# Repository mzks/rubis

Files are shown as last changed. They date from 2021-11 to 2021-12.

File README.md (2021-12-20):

# rubis








ADC board for 16 channels Slow Control on Raspberry pi.
This repository provides board design and control software.

## Demo
 - 30 seconds to start

rubis_demo_comp

 - Web watching demo
demo
It is easy to watch your sensors with rubis + Grafana

 - PCB view on Raspbery Pi


## Feature

 - Standalone
 - Inexpensive
 - Multi channels (16 ch) and additional connectors (4 ch)
 - Including CLI software (This!)

## Hardware components
 - rubis board - less than 5 dollars at elecrow 
 - Raspberry Pi (1B+, 2B, 3B, 3B+, 4B, Zero)
 - [PIN Socket](https://akizukidenshi.com/catalog/g/gC-00085/) 
 - [ADC Board](https://www.marutsu.co.jp/pc/i/574270/) * 1--4 / 20 dollers per board
 - [BNC Connector](https://akizukidenshi.com/catalog/g/gC-00134/) ( * 4, optional)
 - [SMA Connector](https://akizukidenshi.com/catalog/g/gC-02569/) ( * 4, optional)
 - LEMO Connector (Optional)

## Hardware

You need to connect the four GPIO pins arranged in a square (Pin 3 -- SDA, Pin 4 -- 5V, Pin 5 -- SCL, Pin 6 -- GND).
 - [Circuit diagram](https://github.com/mzks/rubis/blob/main/hardware/rubis_circuit.pdf)
 - [3D view](https://github.com/mzks/rubis/blob/main/hardware/rubis.step)
 - [KiCad files](https://github.com/mzks/rubis/blob/main/hardware)

## Software

### Install
Before run, enable I2C on Raspberry Pi. (`sudo raspi-config`)
Then, you can find the i2c devices like this.
```
> sudo i2cdetect -y 1
     0  1  2  3  4  5  6  7  8  9  a  b  c  d  e  f
00:          -- -- -- -- -- -- -- -- -- -- -- -- --
10: -- -- -- -- -- -- -- -- -- -- -- -- -- -- -- --
20: -- -- -- -- -- -- -- -- -- -- -- -- -- -- -- --
30: -- -- -- -- -- -- -- -- -- -- -- -- -- -- -- --
40: -- -- -- -- -- -- -- -- 48 49 4a 4b -- -- -- --
50: -- -- -- -- -- -- -- -- -- -- -- -- -- -- -- --
60: -- -- -- -- -- -- -- -- -- -- -- -- -- -- -- --
70: -- -- -- -- -- -- -- --
```
If you will use an old raspberry pi, run `sudo apt install libatlas-base-dev` to use `numpy` (This tool doesn't depend on `numpy`).

Then, type `pip3 install rubis`
The `rubis` binary will be provided at `~/.local/bin/rubis`
You want mysql store, please see `Database setting` below.

### Usage
When you execute `rubis` without option, logging immidiately starts with default configurations.
You can use your custom configuration file with `-c` option.

`rubis -g` generates template config file.
Edit them, then run `rubis -c custom_config.json`.
At the **strong** request of the author's supervisor, the following commands are available to people in CYGNUS (dark matter search experiment) without creating or editing a new configuration file.
```
rubis -c cygnus
```
In addition of `cygnus`, `one_board` and `mysql` configurations are pre-defined.

Some configurations can be overwrited with command line options.
`rubis -h` provides option descriptions.
The output file format is CSV/MySQL.

As a default, the csv files like `sc-20211029-75enrt.csv` are created.
The `75enrt` is a unique hash created by configurations.
The hash helps separation not to mix files taken with different configurations.
The CSV format is like that.
```
time,ch1,ch2,ch3,ch4,ch5,ch6,ch7,ch8,ch9,ch10,ch11,ch12,ch13,ch14,ch15,ch16
2021-10-29 00:49:50, 0.5481417, 0.5476417, 0.5483917, 0.5476417, 0.5432666, 0.5430166, 0.5441416, 0.5433916, 0.5486417, 0.5478917, 0.5482667, 0.5477667, 0.5441416, 0.5446416, 0.5440166, 0.5440166
2021-10-29 00:50:51, 0.5486417, 0.5483917, 0.5475167, 0.5476417, 0.5437666, 0.5435166, 0.5435166, 0.5436416, 0.5482667, 0.5483917, 0.5485167, 0.5481417, 0.5451416, 0.5451416, 0.5438916, 0.5437666
2021-10-29 00:51:51, 0.5480167, 0.5478917, 0.5480167, 0.5475167, 0.5432666, 0.5431416, 0.5430166, 0.5437666, 0.5482667, 0.5481417, 0.5481417, 0.5480167, 0.5445166, 0.5436416, 0.5443916, 0.5443916
2021-10-29 00:52:51, 0.5487667, 0.5481417, 0.5481417, 0.5481417, 0.5437666, 0.5437666, 0.5438916, 0.5435166, 0.5487667, 0.5482667, 0.5483917, 0.5478917, 0.5448916, 0.5440166, 0.5442666, 0.5438916
2021-10-29 00:53:52, 0.5482667, 0.5486417, 0.5476417, 0.5477667, 0.5438916, 0.5437666, 0.5432666, 0.5435166, 0.5487667, 0.5481417, 0.5481417, 0.5485167, 0.5445166, 0.5440166, 0.5441416, 0.5440166
2021-10-29 00:54:52, 0.5482667, 0.5478917, 0.5477667, 0.5478917, 0.5433916, 0.5430166, 0.5436416, 0.5438916, 0.5487667, 0.5487667, 0.5488918, 0.5478917, 0.5451416, 0.5447666, 0.5442666, 0.5441416
2021-10-29 00:55:53, 0.5487667, 0.5480167, 0.5478917, 0.5475167, 0.5441416, 0.5437666, 0.5435166, 0.5433916, 0.5487667, 0.5480167, 0.5483917, 0.5482667, 0.5452666, 0.5450166, 0.5448916, 0.5441416
2021-10-29 00:56:53, 0.5487667, 0.5483917, 0.5482667, 0.5481417, 0.5440166, 0.5438916, 0.5441416, 0.5443916, 0.5491418, 0.5487667, 0.5483917, 0.5482667, 0.5446416, 0.5442666, 0.5441416, 0.5445166
2021-10-29 00:57:54, 0.5478917, 0.5483917, 0.5480167, 0.5480167, 0.5441416, 0.5438916, 0.5440166, 0.5442666, 0.5491418, 0.5488918, 0.5488918, 0.5481417, 0.5450166, 0.5443916, 0.5441416, 0.5442666
```

The `-r` option makes "dry-run".
With the option, this rubis works on general system not raspberry pi even without ADS board.
It helps to know how rubis works.

The `-l` option show rubis log.
It helps to find the logfile place and configuration with hash.

If you miss a config to generate hash, `-b` option helps you.
`rubis -b g2hlpc` generates the config file run before.

The `-q` option kill all rubis processes.
With the `-s` option, rubis uses the stored cofiguration used in the previous run.

For analysis with pandas dataframe, it is easy to extract the csv files.
```
import pandas as pd
from glob import glob

hash_str = '75enrt'
df = [pd.read_csv(name, parse_dates=[0], index_col=0) for name in sorted(glob('./*'+hash_str+'.csv'))]
df = pd.concat(df)
```

### Config option

| Configure name | Description | Option | Overwrite option |
| --- | --- | --- | --- |
| `path` | Path to store the data | Default: "./" | -p |
| `file_header` | File header of generated file | Default: "sc" | -f |
| `naming` | Naming style of file | `'date_hash.csv'`, etc. Available keywords : 'head', 'date', 'id', 'hash', 'host' | -n |
| `rubis_id` | rubis id (string) | Used to identify your rubis board | -i |
| `time_interval_sec` | Data taking time interval (sec)  | Default: 10 | -t |
| `available_boards`  | List of available ADS1115 boards | Default: [1,2,3,4] | -a |
| `output` | Output format | `"csv"`, `"db"`, or `"both"` | -o |
| `delimiter` | Delimiter for csv output | `","`, `" "`, `"space"`, etc. | -d |
| `commentout_string` | Strings to be added on the csv file header | default: "" | |
| `time_format` | Time column format | "timestamp", "datetime" (default), or strftime format (for example, "%H:%M:%S") |  |
| `boards` | Setting for each ADS1115 board | `"gain"` option is available | |
| `sources` | Setting for each channels | | |

If you select `naming` including "date", a new file will be created day by day.

The sources should be set like,
```
"1":{
    "name": "ch1",
    "description": "channel 1",
    "type": "volt"
    },
"2":{
    "name": "ch2",
    "description": "channel 2",
    "type": "linear"
    "a": 2.0,
    "b": 1.2
    },
```
The `name` is used for csv header. For the `type`, `"volt"`, `"raw"`, `"millivolt"`, and `"linear"` are available.
`"linear"` returns the value `"a" * (volt) + "b"`. The "a" and "b" should be written in the config file, for each sources.

## Database setting
If you want database store, do like that additionaly
```
sudo apt install mariadb-server
sudo mysql -u root
MariaDB [(none)]> UPDATE mysql.user SET password=password('newpassword') WHERE User = 'root';
MariaDB [mysql]> UPDATE mysql.user SET plugin='' WHERE User='root';
MariaDB [mysql]> GRANT ALL PRIVILEGES ON *.* TO 'root'@'localhost' identified by 'newpassword' with grant option;
MariaDB [mysql]> exit
sudo systemctl restart mysql
```
You need an external access, please make a user.
```
CREATE USER 'rubis'@'10.37.%' IDENTIFIED BY 'password';
GRANT ALL ON *.* TO 'rubis'@'10.37.%';
FLUSH PRIVILEGES;
```
And comment out the `bind-address` line in `/etc/mysql/mariadb.conf.d/50-server.cnf`.
In addition, add `default_time_zone='+00:00'` at the bottom of the file.
Then run `sudo systemctl restart mysql`.

If you need static IP access, please edit `/etc/dhcpcd.conf` like this.
```
# Example static IP configuration:
interface eth0
static ip_address=***.***.***.***/** # your IP/mask
static routers=***.***.***.*** # your gateway
static domain_name_servers=***.***.***.*** ***.***.***.*** # your DNS
```

When you set `"db"` or `"both"` for `output` in config file, the following settings are required.
```
"db":{
    "login":{
        "host": "127.0.0.1",
        "port": 3306,
        "user": "root",
        "passwd": "newpassword",
        "autocommit": true},
    "name": "rubis"
    }
```

## For developers
Clone this repository on your machine, then run `make.sh`.
If you need something, please feel free to send a PR or ask me on issue.

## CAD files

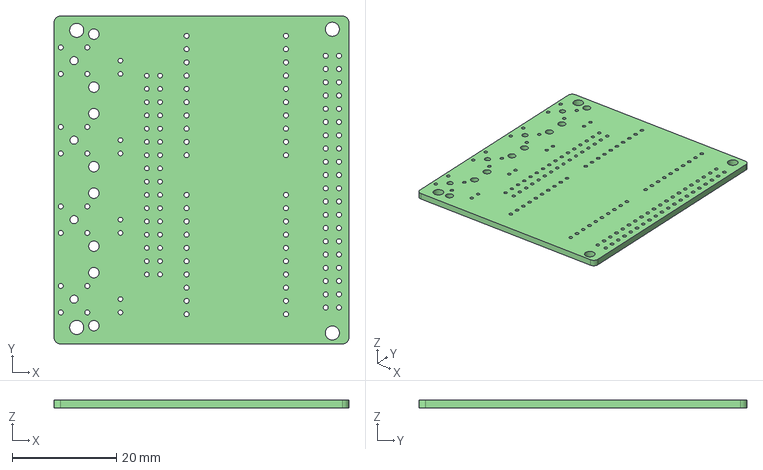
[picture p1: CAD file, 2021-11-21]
hardware/rubis.step
56.5 x 62.9 x 1.60 mm

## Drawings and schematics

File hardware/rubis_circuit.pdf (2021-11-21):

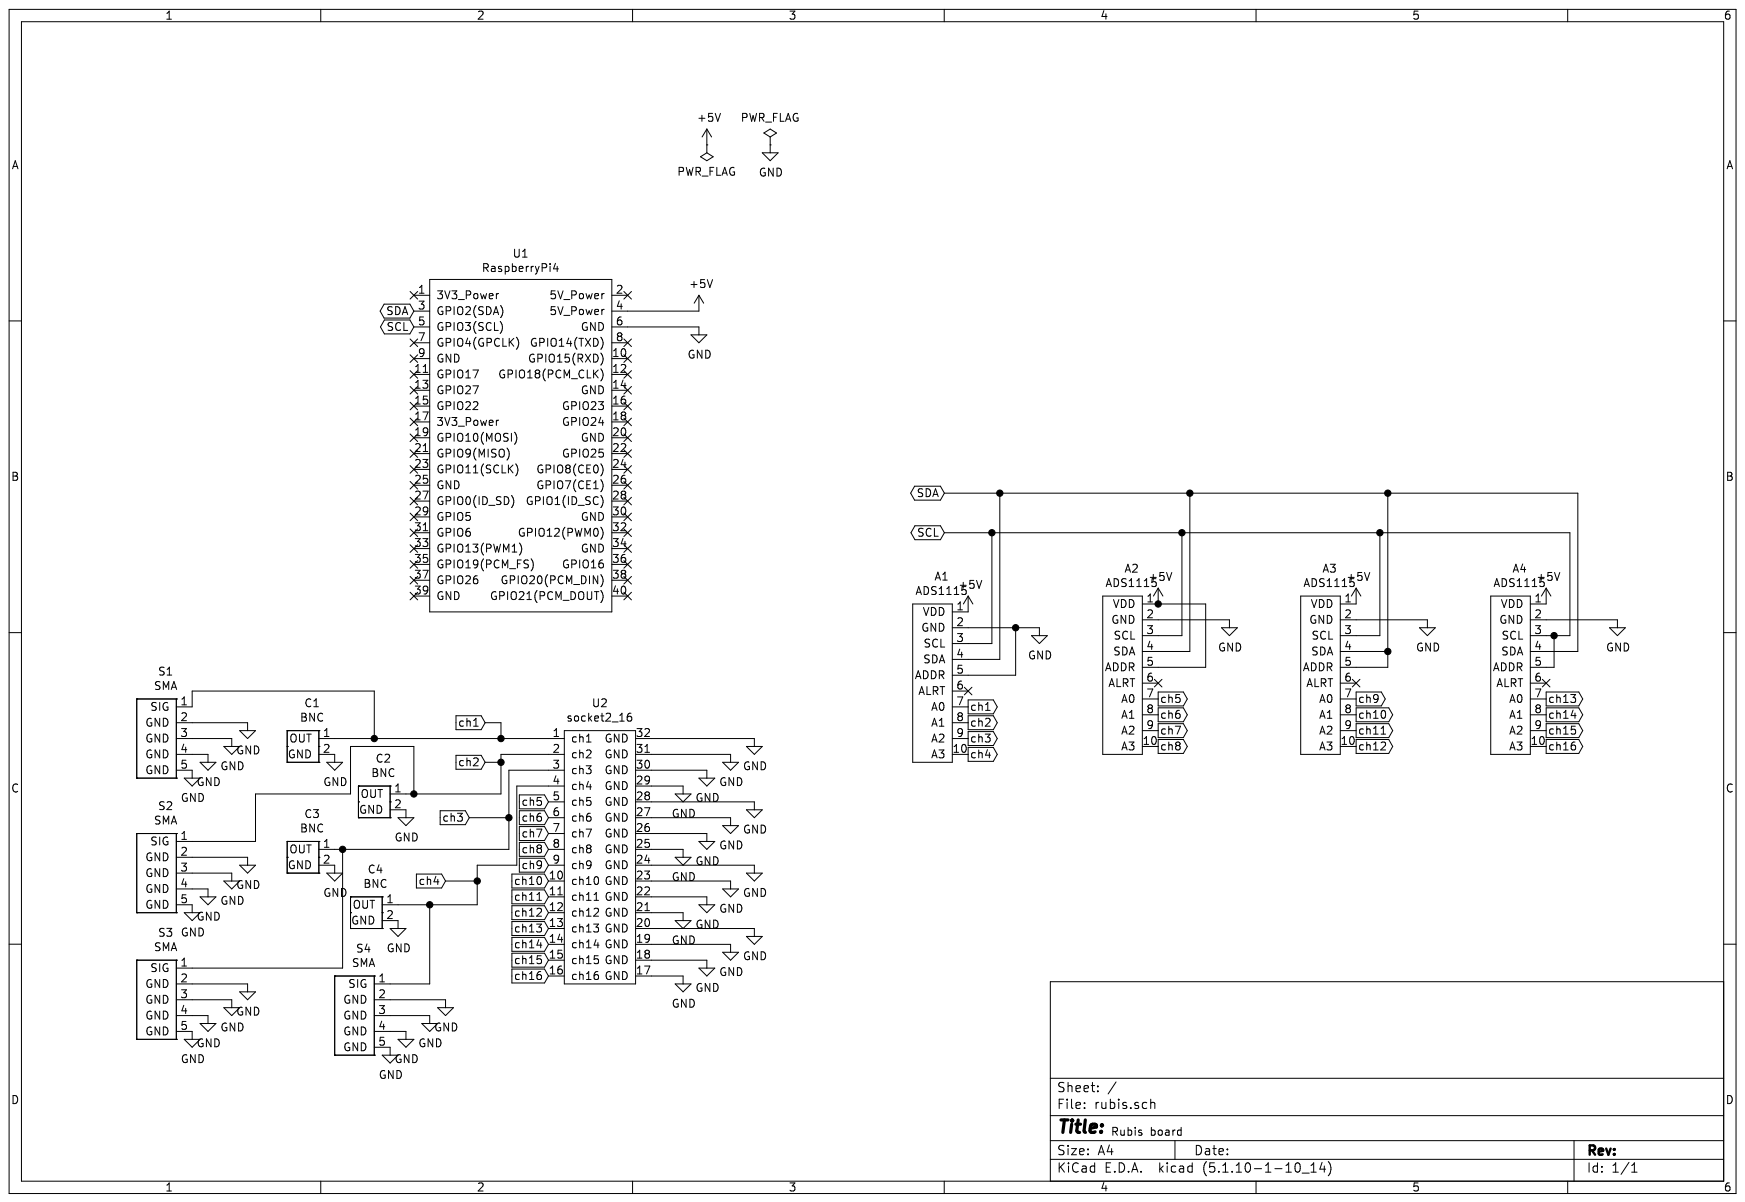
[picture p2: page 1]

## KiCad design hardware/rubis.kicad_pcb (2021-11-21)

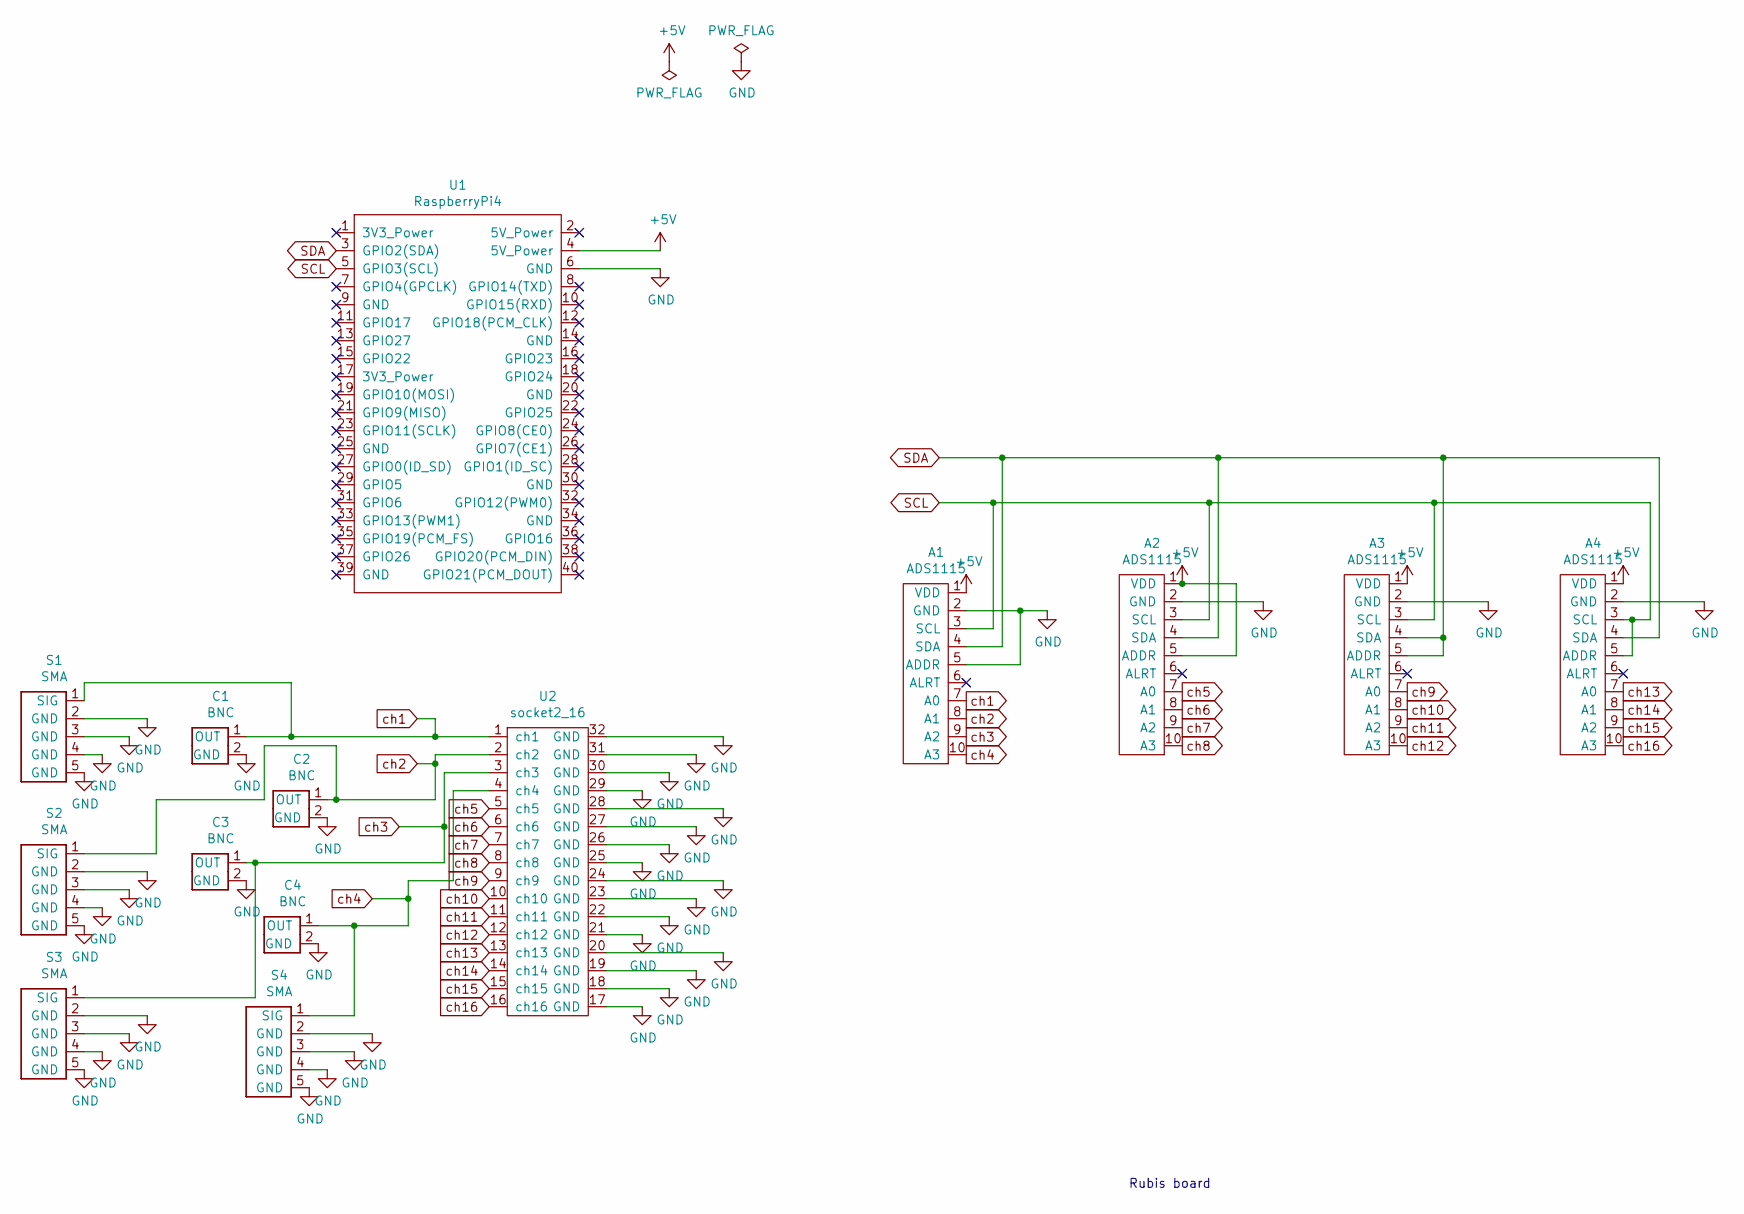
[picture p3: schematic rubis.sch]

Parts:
A1, A2, A3, A4: ADS1115; ads1115
C1, C2, C3, C4: BNC
S1, S2, S3, S4: SMA
U1: RaspberryPi4; rasp_40pin
U2: socket2_16; 2_16_socket

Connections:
+5V: A1.1 (VDD), A2.1 (VDD), A2.5 (ADDR), A3.1 (VDD), A4.1 (VDD), U1.4 (5V_Power); also elsewhere on the board
GND: A1.2 (GND), A1.5 (ADDR), A2.2 (GND), A3.2 (GND), A4.2 (GND), C1.2 (GND), C2.2 (GND), C3.2 (GND), C4.2 (GND), S1.2 (GND), S1.3 (GND), S1.4 (GND), S1.5 (GND), S2.2 (GND), S2.3 (GND), S2.4 (GND), S2.5 (GND), S3.2 (GND), S3.3 (GND), S3.4 (GND), S3.5 (GND), S4.2 (GND), S4.3 (GND), S4.4 (GND), S4.5 (GND), U1.6 (GND), U2.17 (GND), U2.18 (GND), U2.19 (GND), U2.20 (GND), U2.21 (GND), U2.22 (GND), U2.23 (GND), U2.24 (GND), U2.25 (GND), U2.26 (GND), U2.27 (GND), U2.28 (GND), U2.29 (GND), U2.30 (GND), U2.31 (GND), U2.32 (GND); also elsewhere on the board
SCL: A1.3 (SCL), A2.3 (SCL), A3.3 (SCL), A4.3 (SCL), A4.5 (ADDR), U1.5 (GPIO3(SCL)); also elsewhere on the board
SDA: A1.4 (SDA), A2.4 (SDA), A3.4 (SDA), A3.5 (ADDR), A4.4 (SDA), U1.3 (GPIO2(SDA)); also elsewhere on the board
ch1: A1.7 (A0), C1.1 (OUT), S1.1 (SIG), U2.1 (ch1); also elsewhere on the board
ch2: A1.8 (A1), C2.1 (OUT), S2.1 (SIG), U2.2 (ch2); also elsewhere on the board
ch3: A1.9 (A2), C3.1 (OUT), S3.1 (SIG), U2.3 (ch3); also elsewhere on the board
ch4: A1.10 (A3), C4.1 (OUT), S4.1 (SIG), U2.4 (ch4); also elsewhere on the board
ch5: A2.7 (A0), U2.5 (ch5)
ch6: A2.8 (A1), U2.6 (ch6)
ch7: A2.9 (A2), U2.7 (ch7)
ch8: A2.10 (A3), U2.8 (ch8)
ch9: A3.7 (A0), U2.9 (ch9)
ch10: A3.8 (A1), U2.10 (ch10)
ch11: A3.9 (A2), U2.11 (ch11)
ch12: A3.10 (A3), U2.12 (ch12)
ch13: A4.7 (A0), U2.13 (ch13)
ch14: A4.8 (A1), U2.14 (ch14)
ch15: A4.9 (A2), U2.15 (ch15)
ch16: A4.10 (A3), U2.16 (ch16)

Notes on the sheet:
Rubis board

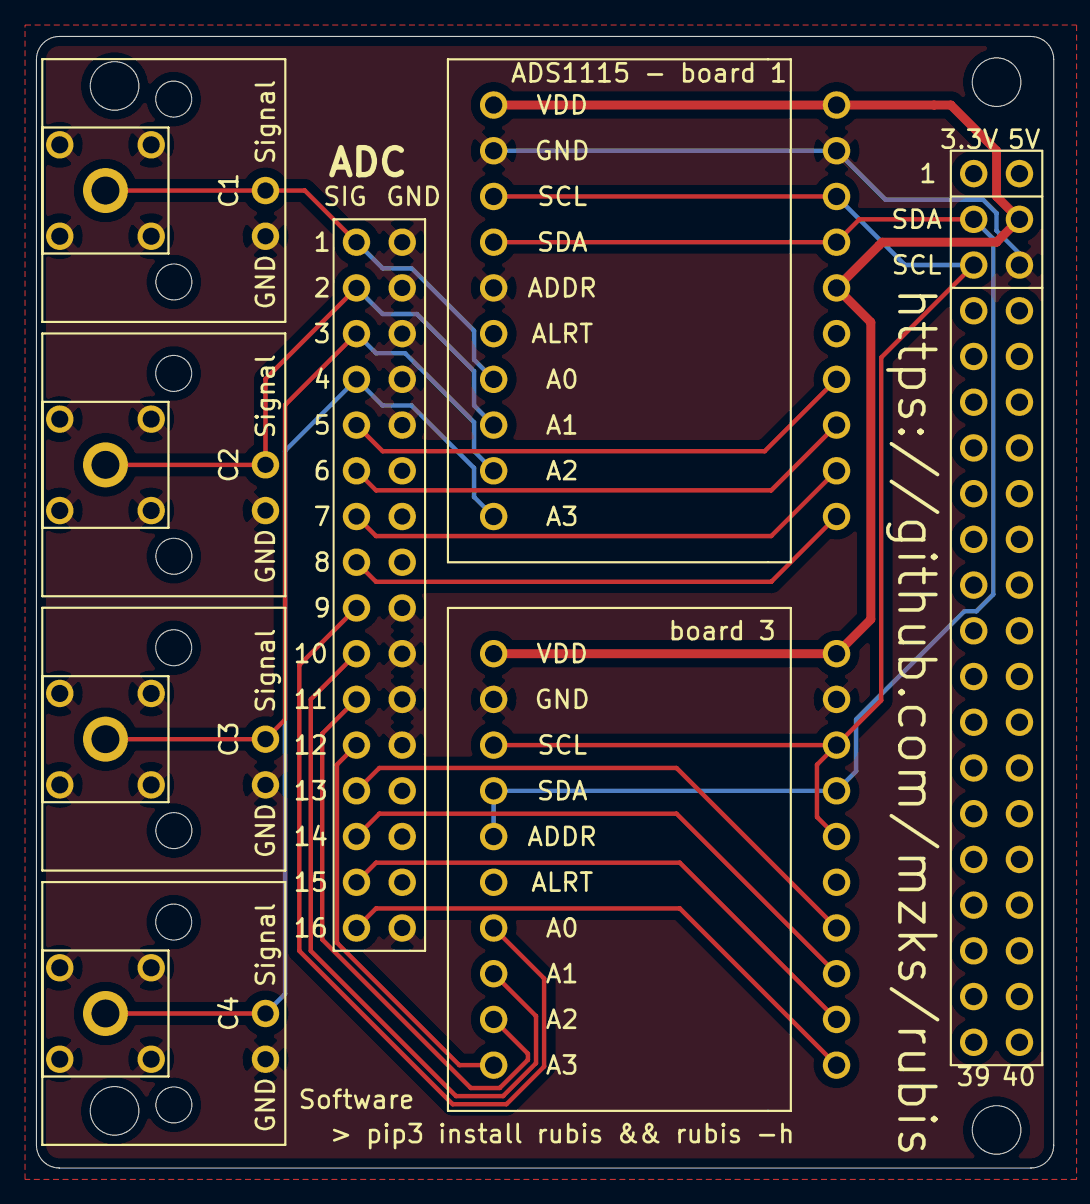
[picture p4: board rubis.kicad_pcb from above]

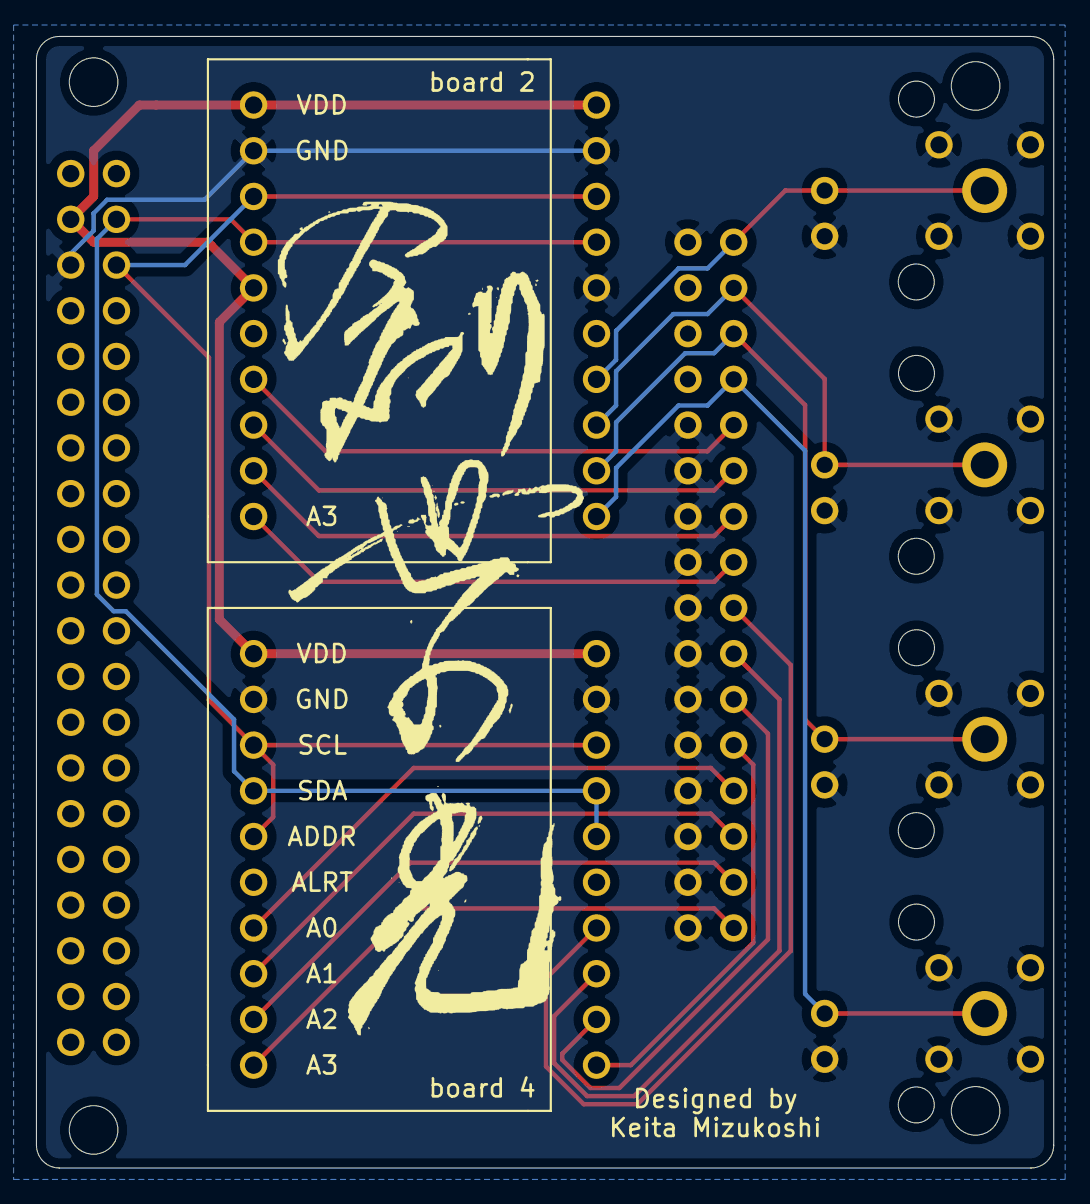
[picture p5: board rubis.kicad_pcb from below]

Board: 2 copper layers, 56.5 x 62.9 mm, 14 parts (2 on the bottom side), 20 nets.

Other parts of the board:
ADS1115 - board 1: ADS1115; ads1115

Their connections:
+5V: ADS1115 - board 1.1; also elsewhere on the board
GND: ADS1115 - board 1.2, ADS1115 - board 1.5; also elsewhere on the board
SCL: ADS1115 - board 1.3; also elsewhere on the board
SDA: ADS1115 - board 1.4; also elsewhere on the board
ch1: ADS1115 - board 1.7; also elsewhere on the board
ch2: ADS1115 - board 1.8; also elsewhere on the board
ch3: ADS1115 - board 1.9; also elsewhere on the board
ch4: ADS1115 - board 1.10; also elsewhere on the board

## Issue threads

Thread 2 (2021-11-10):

path in cofig file is not loaded

miuchi, 2021-11-10:
branch pushできなかったので書いときます。
  core.pyの下から3行目に
    outfilename=config['path']+outfilename
加えました。
コマンドラインの方はひとまず無視してます。

その他オレオレ仕様をconfigに加えて使ってます。

mzks, 2021-11-11:
Fixed in #2

Closed 2021-11-11.

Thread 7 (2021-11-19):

circuit and layout diagrams in PDF

SatoshiHiggs, 2021-11-19:
I'll be happy if we can get the circuit and layout diagrams not only in the KiCAD format but PDF...!

mzks, 2021-11-19:
https://github.com/mzks/rubis/blob/main/hardware/circuit.pdf

Closed 2021-11-19.

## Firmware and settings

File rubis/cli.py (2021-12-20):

import os
import re
import argparse
import json
import shutil
import pkg_resources

from rubis.core import run, add_log, show_log


def read_jsonc(filepath: str):
    with open(filepath, 'r', encoding='utf-8') as f:
        text = f.read()
    re_text = re.sub(r'/\*[\s\S]*?\*/|//.*', '', text)
    json_obj = json.loads(re_text)
    return json_obj


def main():

    parser = argparse.ArgumentParser(description='Rubis Control tool')
    parser.add_argument('-c', '--config', default='default_config', help='Config json filename with path')
    parser.add_argument('-g', '--generate_config', action='store_true', help='Generate config example')
    parser.add_argument('-t', '--time_interval_sec', default=0., help='Time interval to collect data', type=float)
    parser.add_argument('-o', '--output', default='default', choices=['default', 'csv', 'db', 'both'],
                        help='Output style (file or database)')
    parser.add_argument('-p', '--path', default='default', help='File output path')
    parser.add_argument('-n', '--naming', default='default',
                        help='File naming style e.g., date-hash-id.csv etc.')
    parser.add_argument('-f', '--file_header', default='default', help='File header')
    parser.add_argument('-i', '--rubis_id', default='default', help='Rubis ID')
    parser.add_argument('-d', '--delimiter', default='default', help='Delimiter for csv output')
    parser.add_argument('-a', '--available_boards', default=[], type=int, nargs='+',
                        help='Available board numbers e.g., -a 1 3')
    parser.add_argument('-r', '--dryrun', action='store_true', help='Generate dummy files even not on RaspPi.')
    parser.add_argument('-b', '--booked', default=None, help='Find configure file booked.')
    parser.add_argument('-s', '--stored', action='store_true', help='Use the previous configuration stored')
    parser.add_argument('-l', '--log', action='store_true', help='Show all log')
    parser.add_argument('-q', '--quit', action='store_true', help='Kill all running rubis')
    parser.add_argument('-v', '--version', action='store_true')
    # ejkmquwxyz

    args = parser.parse_args()
    version = '1.0.0'
    if args.version:
        print('rubis version : ' + version)
        return

    if args.quit:
        import psutil
        pids = psutil.pids()
        self_pid = os.getpid()
        for pid in pids:
            if pid == self_pid:
                continue
            try:
                p = psutil.Process(pid)
                cmd = ''.join(p.cmdline())
                if (cmd.find('rubis') != -1) & (cmd.find('rubis-q') == -1):
                    p.kill()
                    add_log('Killed PID: ' + str(pid))
            except:
                pass
        return

    if args.log:
        show_log()
        return

    if args.booked != None:
        config_filename = pkg_resources.resource_filename('rubis', 'data') + '/' + args.booked + '.json'
        if os.path.exists(config_filename):
            shutil.copyfile(config_filename, './'+args.booked+'.json')
        else:
            print(args.booked + '.json does not exist. Nothing to do.')
        return

    if args.generate_config:
        config_filename = pkg_resources.resource_filename('rubis', 'data') + '/default_config.json'
        if os.path.exists('./custom_config.json'):
            print('custom_config.json exists in this directory. Nothing to do.')
            return
        shutil.copyfile(config_filename, './custom_config.json')
        return

    if args.config == 'default_config':
        config_filename = pkg_resources.resource_filename('rubis', 'data') + '/default_config.json'
    else:
        config_filename = pkg_resources.resource_filename('rubis', 'data') + '/' + args.config
        if os.path.exists(config_filename):
            pass
        else:
            config_filename = args.config

    if args.stored:
        config_filename = pkg_resources.resource_filename('rubis', 'data') + '/.previous_config.json'
        if os.path.exists(config_filename):
            pass
        else:
            config_filename = pkg_resources.resource_filename('rubis', 'data') + '/default_config.json'

    print('Use config ' + config_filename)

    config = read_jsonc(config_filename)
    if args.path != 'default':
        config['path'] = args.path
    if config['path'][-1] != '/':
        config['path'] = config['path'] + '/'
    if args.file_header != 'default':
        config['file_header'] = args.file_header
    if args.naming != 'default':
        config['naming'] = args.naming
    if args.output != 'default':
        config['output'] = args.output
    if args.rubis_id != 'default':
        config['rubis_id'] = args.rubis_id
    if args.available_boards:
        config['available_boards'] = args.available_boards
    if args.delimiter == 'space':
        config['delimiter'] = ' '
    elif args.delimiter != 'default':
        config['delimiter'] = args.delimiter
    if config['delimiter'] == 'space':
        config['delimiter'] = ' '
    if args.time_interval_sec > 0:
        config['time_interval_sec'] = args.time_interval_sec

    filename = pkg_resources.resource_filename('rubis', 'data') + '/.previous_config.json'
    config_json = open(filename, "w")
    json.dump(config, config_json, indent=4)
    config_json.close()

    run(config, args.dryrun)


if __name__ == "__main__":
    main()

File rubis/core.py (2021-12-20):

import os
import socket
import time
import math
import datetime
import json
import pkg_resources
import pathlib

from rubis.hash import deterministic_hash


class dummy_ch:
    def __init__(self):
        self._t = 0

    @property
    def value(self):
        self._t += 1
        return 32768 + int(1000 * math.sin(self._t/20))

    @property
    def voltage(self):
        self._t += 1
        return 2. + 1. * math.sin(self._t/20)


def run(config, dryrun):

    config_hash = deterministic_hash(config, 6)
    config_json = open(config['path'] + config_hash + ".json", "w")
    json.dump(config, config_json, indent = 4)
    config_json.close()

    config_json = open(pkg_resources.resource_filename('rubis', 'data') + '/' + config_hash + ".json", "w")
    json.dump(config, config_json, indent = 4)
    config_json.close()

    if not dryrun:
        import board
        import busio
        import adafruit_ads1x15.ads1115 as ADS
        from adafruit_ads1x15.analog_in import AnalogIn

        i2c = busio.I2C(board.SCL, board.SDA)
        # Four boards are inplemented (ADDR <-> GND, Vdd, SDA, SCL)
        board_address = {"1": 0x48, "2": 0x49, "3": 0x4A, "4": 0x4B}
        try:
            adss = [ADS.ADS1115(i2c, address=board_address[str(board_id)]) for board_id in config['available_boards']]
            chs = []
            for ads, board_id in zip(adss, config['available_boards']):
                ads.gain = config['boards'][str(board_id)]['gain']
                chs.append(AnalogIn(ads, ADS.P0))
                chs.append(AnalogIn(ads, ADS.P1))
                chs.append(AnalogIn(ads, ADS.P2))
                chs.append(AnalogIn(ads, ADS.P3))
        except:
            print('Please check your ADC boards availavility')
            print("See 'available_boards' configuration or '-a'")

    else: # dryrun
        adss = [board_id for board_id in config['available_boards']]
        chs = []
        for ads, board_id in zip(adss, config['available_boards']):
            for i in range(4):
                chs.append(dummy_ch())

    sources, ch_str = [], []
    for board_id in config['available_boards']:
        for ch in range(4):
            ch_id = str((int(board_id) - 1) * 4 + ch + 1)
            ch_str.append(ch_id)
            sources.append(config['sources'][ch_id])


    print('Data taking on the hash '+config_hash)
    a_path = str(pathlib.Path(config['path']).resolve())
    add_log('Start on hash ' + config_hash +' in ' + a_path + ' PID :' + str(os.getpid()))

    ocsv, odb = True, False
    if config['output'] == 'db':
        ocsv, odb = False, True
    if config['output'] == 'both':
        ocsv, odb = True, True
    if odb:
        import pymysql.cursors
        conn = pymysql.connect(**config['db']['login'])
        cursor = conn.cursor()
        cursor.execute("CREATE DATABASE IF NOT EXISTS " + config['db']['name'])
        cursor.execute("USE " + config['db']['name'])
        cursor.execute('''
                        CREATE TABLE IF NOT EXISTS data (id INT AUTO_INCREMENT, 
                        time TIMESTAMP not null default CURRENT_TIMESTAMP, 
                        ch1 FLOAT, ch2 FLOAT, ch3 FLOAT, ch4 FLOAT, ch5 FLOAT, ch6 FLOAT,
                        ch7 FLOAT, ch8 FLOAT, ch9 FLOAT, ch10 FLOAT, ch11 FLOAT, ch12 FLOAT,
                        ch13 FLOAT, ch14 FLOAT, ch15 FLOAT, ch16 FLOAT, hash VARCHAR(6), 
                        rubis_id VARCHAR(10), log_time DATETIME,
                        PRIMARY KEY (id))
                        ''')
        sql = ('''
                INSERT INTO data (log_time, ch1, ch2, ch3, ch4, ch5, ch6, ch7, ch8, ch9, ch10,
                ch11, ch12, ch13, ch14, ch15, ch16, hash, rubis_id)
                VALUES (%s, %s, %s, %s, %s, %s, %s, %s, %s, %s, %s, %s, %s, %s, %s, %s, %s, %s, %s)
               ''')
        
    delim = config['delimiter']
    commentout_string = config['commentout_string']

    while True:
        now = datetime.datetime.now()
        date = now.strftime("%Y%m%d")
        if config['time_format'] == 'timestamp':
            time_str = str(int(now.timestamp()))
        elif config['time_format'] == 'datetime':
            time_str = now.strftime("%Y-%m-%d %H:%M:%S")
        else:
            time_str = now.strftime(config['time_format'])
            
        if ocsv:
            outfilename = get_outfilename(config, config_hash, date)
            # File existance check
            if not os.path.isfile(outfilename):
                with open(outfilename, mode='a') as f:
                    f.write(commentout_string+'time')
                    for source in sources:
                        f.write(delim + source['name'])
                    f.write('\n')
            with open(outfilename, mode='a') as f:
                f.write(time_str)

        if odb:
            db_data = [now.strftime("%Y-%m-%d %H:%M:%S")]+["0"]*16+[config_hash,config['rubis_id']]

        for ch, s, ch_st in zip(chs, sources, ch_str):
            value = ch.value
            volt = ch.voltage
            if ocsv:
                with open(outfilename, mode='a') as f:
                    if s['type'] == 'raw':
                        f.write(delim+"{:>5}".format(value))
                    elif (s['type'] == 'volt') or (s['type'] == 'V'):
                        f.write(delim+"{:>5.7f}".format(volt))
                    elif s['type'] == 'millivolt' or (s['type'] == 'mV'):
                        f.write(delim+"{:>5.4f}".format(volt*1.e3))
                    elif s['type'] == 'linear':
                        f.write(delim+"{:>5.4f}".format(volt*s['a']+s['b']))
                    else:
                        f.write(delim)
            if odb:
                if s['type'] == 'raw':
                    db_data[int(ch_st)] = "{:>5}".format(value)
                elif (s['type'] == 'volt') or (s['type'] == 'V'):
                    db_data[int(ch_st)] = "{:>5.7f}".format(volt)
                elif s['type'] == 'millivolt' or (s['type'] == 'mV'):
                    db_data[int(ch_st)] = "{:>5.4f}".format(volt*1.e3)
                elif s['type'] == 'linear':
                    db_data[int(ch_st)] = "{:>5.4f}".format(volt*s['a']+s['b'])


        if ocsv:
            with open(outfilename, mode='a') as f:
                f.write('\n')
        if odb:
            cursor.execute(sql, tuple(db_data))

        time.sleep(config['time_interval_sec'])
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

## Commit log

2021-09-24 KiCAD files
    [rubis.kicad_pcb, rubis.sch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]
2021-10-17 Add socket url
2021-10-20 Upload board pictures
2021-10-21 Add path option (fix)
    [cli.py]
2021-10-21 Print hash on console
2021-10-23 Add insert datetime
2021-10-28 Add description and fix output file format
    [core.py]
2021-11-13 Update available boards option
2021-11-19 Add circuit diagram in pdf
2021-11-21 Remove old hardware files
    [rubis.kicad_pcb, rubis.sch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]
2021-11-21 Add hardware files for rubis 2
    [rubis.kicad_pcb, rubis.sch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]
2021-11-21 Add 3D models
    [rubis.step]
